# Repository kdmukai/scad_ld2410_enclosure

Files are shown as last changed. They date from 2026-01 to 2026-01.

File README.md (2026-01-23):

# ld2410 Human Presence Sensor Enclosure

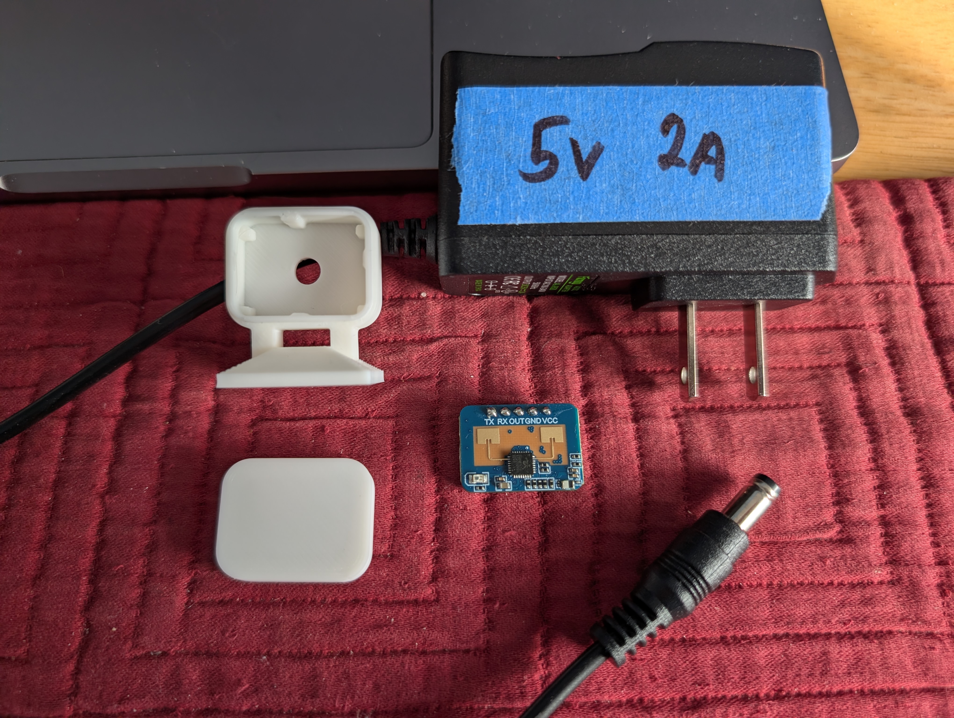
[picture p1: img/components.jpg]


The ld2410 sensor detects human presence even without movement. It broadcasts its data over bluetooth so it can be put to use as a standalone device with just a 5V power supply.

You can then read in the sensor data over bluetooth into Home Assistant to use in automations.

You can also directly connect an ld2410 to an esp32 via ESPHome and receive the data over UART rx/tx, but I find the simplicity of bluetooth to be preferrable (and it's only 2 wires -- VCC and GND -- vs 4 for UART). 

The placement of these sensors around the house is also much more flexible if they are just self-powered and self-broadcasting.

The 3d printed lid does not interfere with its detection abilities.

---

### Design variations
3d printable files include three variants:
* Freestanding pedestal
* Corner wall mount
* Flush wall mount

I used double-sided tape for the wall mounts and under the pedestal to keep it in place.

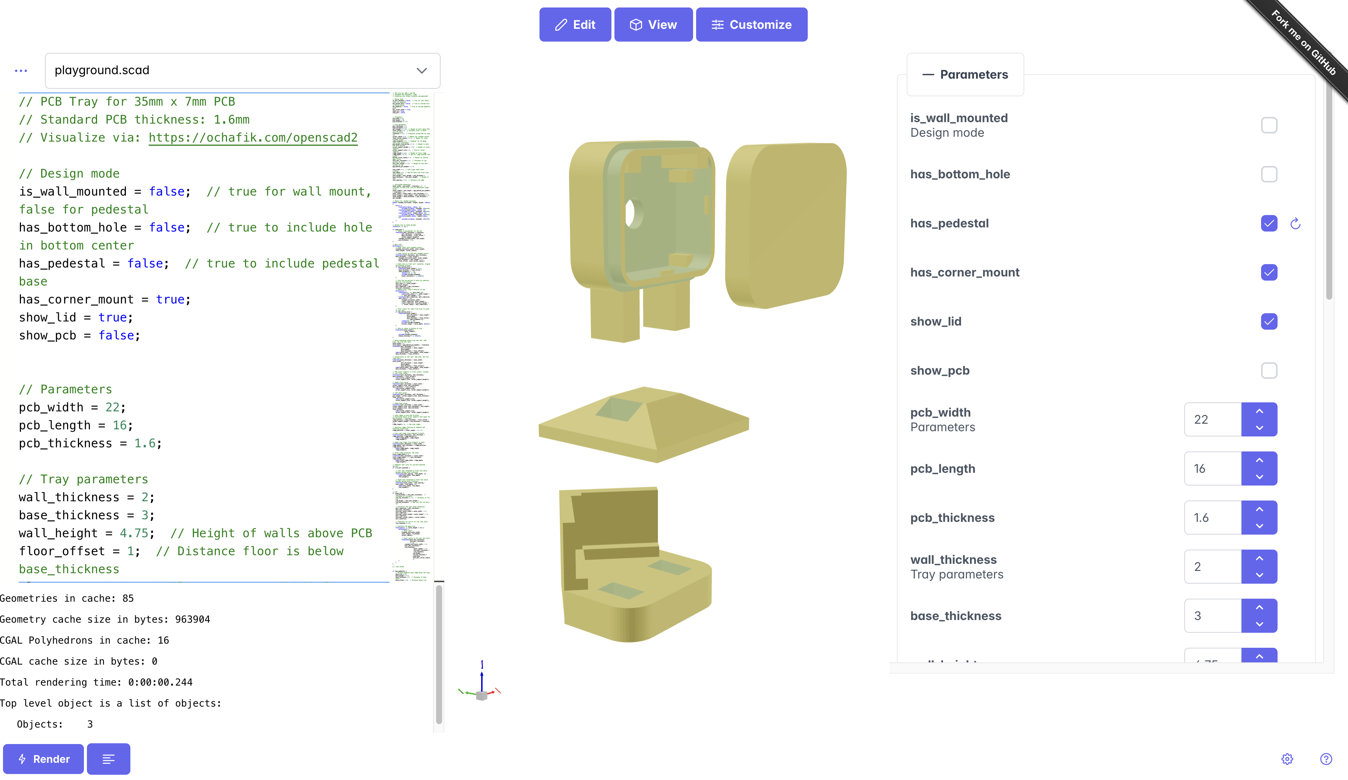
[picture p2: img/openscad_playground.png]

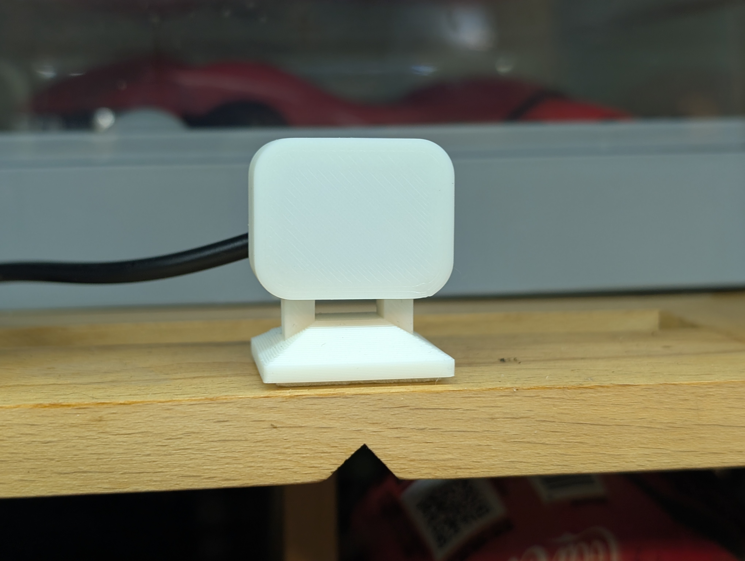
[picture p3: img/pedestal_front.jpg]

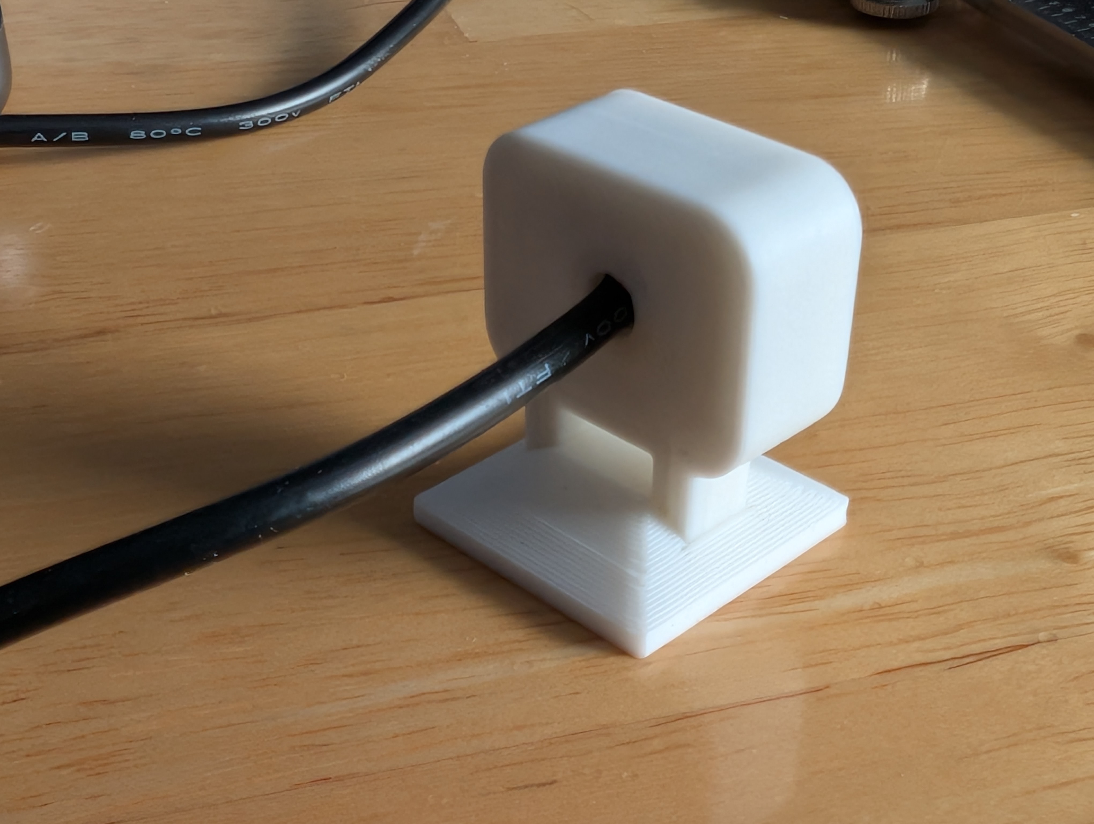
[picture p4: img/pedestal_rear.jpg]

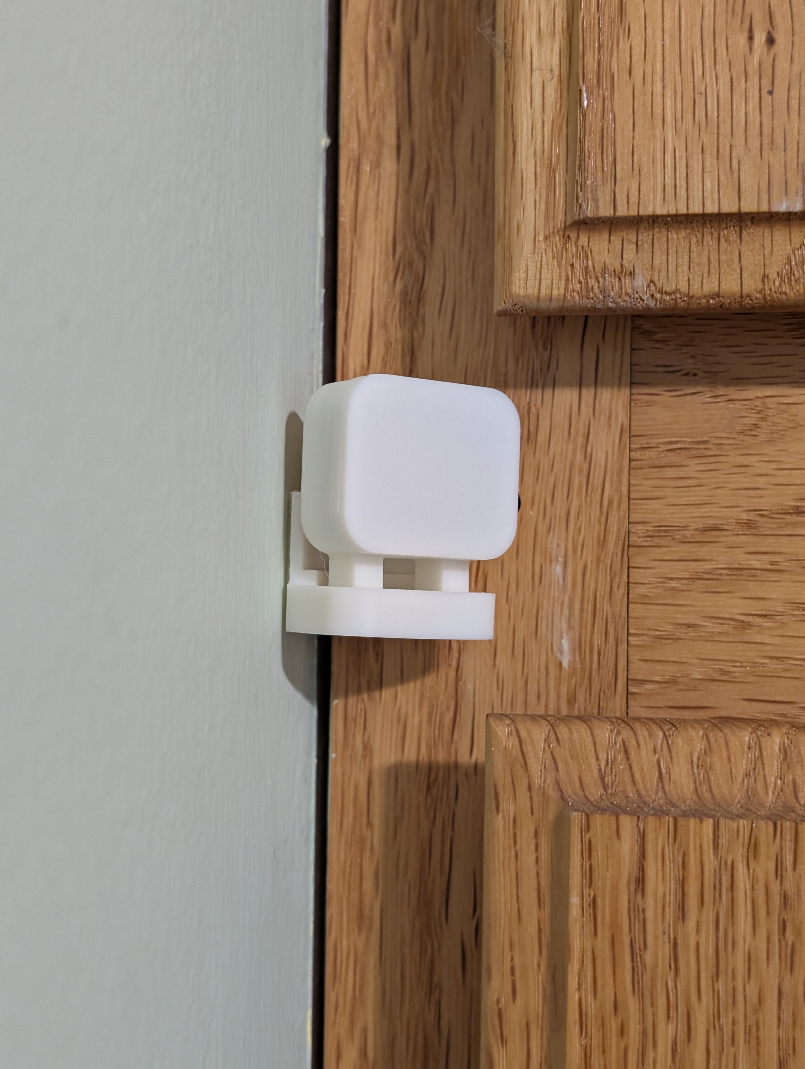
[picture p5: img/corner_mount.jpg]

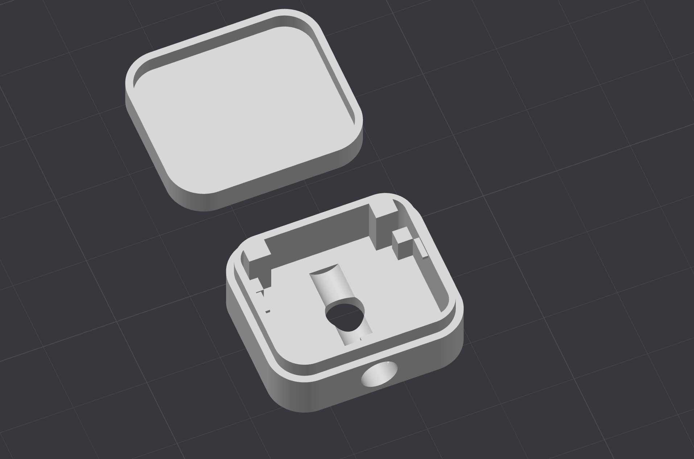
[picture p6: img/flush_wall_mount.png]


---

### Files
* [Customizable SCAD](files/ld2410_enclosure.scad)
* [All variants 3MF](files/ld2410_enclosure.3mf)
* STLs:
  * [Enclosure with feet](files/enclosure_with_feet.stl)
  * [Pedestal](files/pedestal.stl)
  * [Corner mount](files/corner_mount.stl)
  * [Flush wall mount enclosure](files/flush_wall_enclosure.stl)

---

### Components
* ld2410 human presence sensor
* 5V power supply
* solid core 20-22ga patching wire
* soldering iron, solder sucker, solder, flux
* pliers, wire stripper, wire/pin cutter

___

### Assembly
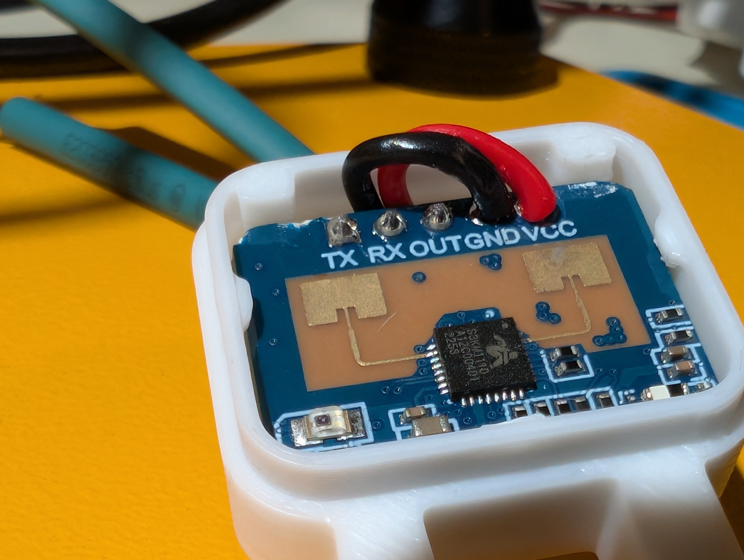
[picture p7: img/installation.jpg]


Remove the black plastic around the headers using a pair of pliers.

Desolder the GND and VCC pins (see [this tutorial](https://www.youtube.com/watch?v=ATeRNgOUX3o&t=114s) for help).

Cut off the remaining pins.

Feed solid core wire through the pin holes and solder in place. I found it easier to apply flux to the back side of the pcb and solder the wires there; soldering them at the front side of the board did not take the flux as easily due to existing solder residue.

Snap the ld2410 into place. There is clearance at the top edge of the board to pass the wires through.

Feed the wires through the enclosure's exit hole.

I then cut off the barrel connector from the power supply and then soldered the leads to the solid core wires and sealed them with heat shrink tubing.

---

### Configuration and Communication
Position the sensor and then adjust its range and sensitivity using the HLKRadarTool app ([Android](https://play.google.com/store/apps/details?id=com.hlk.hlkradartool&hl=en_US), [iOS](https://apps.apple.com/us/app/hlkradartool/id1638651152)).

I set up a `bluetooth_proxy` in ESPHome so that a wifi-connected esp32-s3 uses its antenna to both communicate with Home Assistant and relay data from bluetooth devices.

Home Assistant has a HACS integration to read this bluetooth sensor data: `ha-ld2410`. See: https://www.youtube.com/watch?v=7-VV-X5BpNo

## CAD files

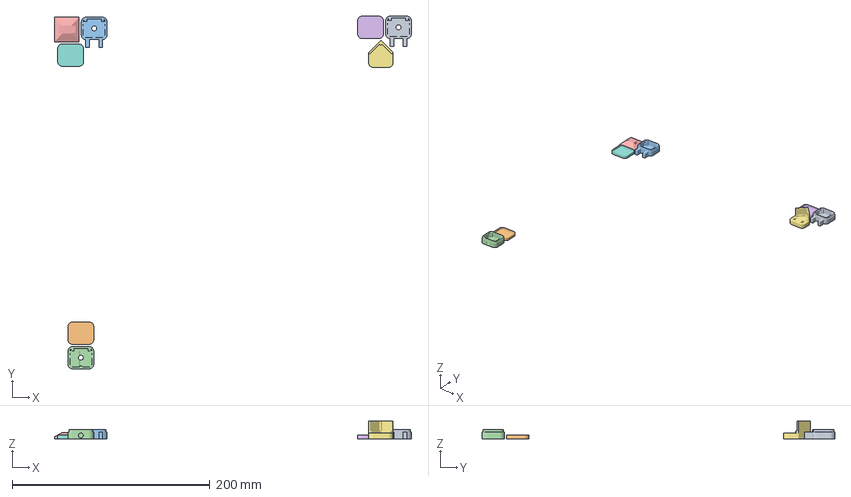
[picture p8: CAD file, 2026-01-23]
files/ld2410_enclosure.3mf
361.1 x 357.0 x 18.1 mm
export (29).stl x 7
export (30).stl

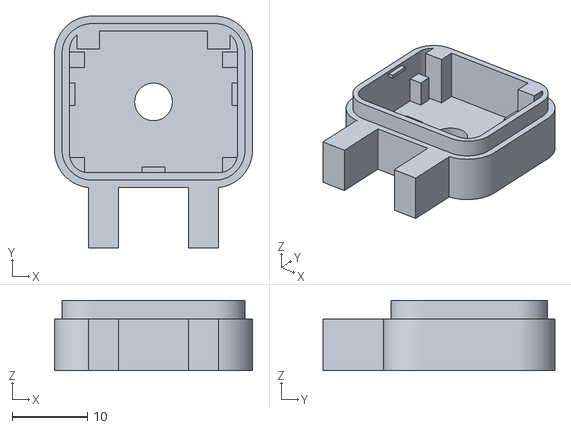
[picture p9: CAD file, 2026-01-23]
files/enclosure_with_feet.stl
26.3 x 30.8 x 9.35

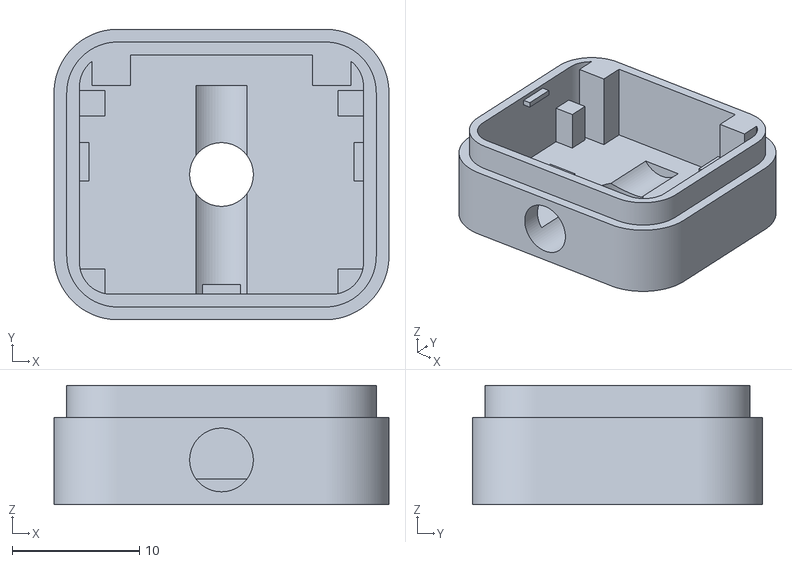
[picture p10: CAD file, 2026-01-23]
files/flush_wall_enclosure.stl
26.3 x 22.8 x 9.35

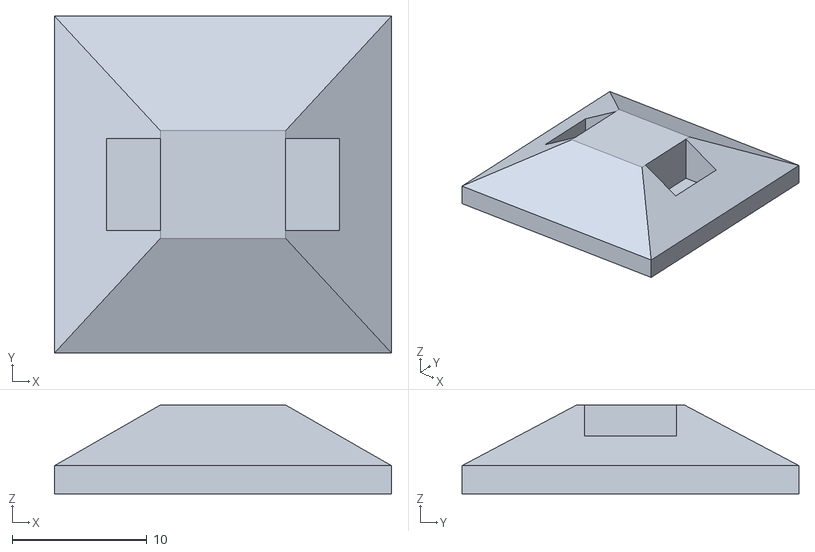
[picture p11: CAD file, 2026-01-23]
files/pedestal.stl
25.0 x 25.0 x 6.60

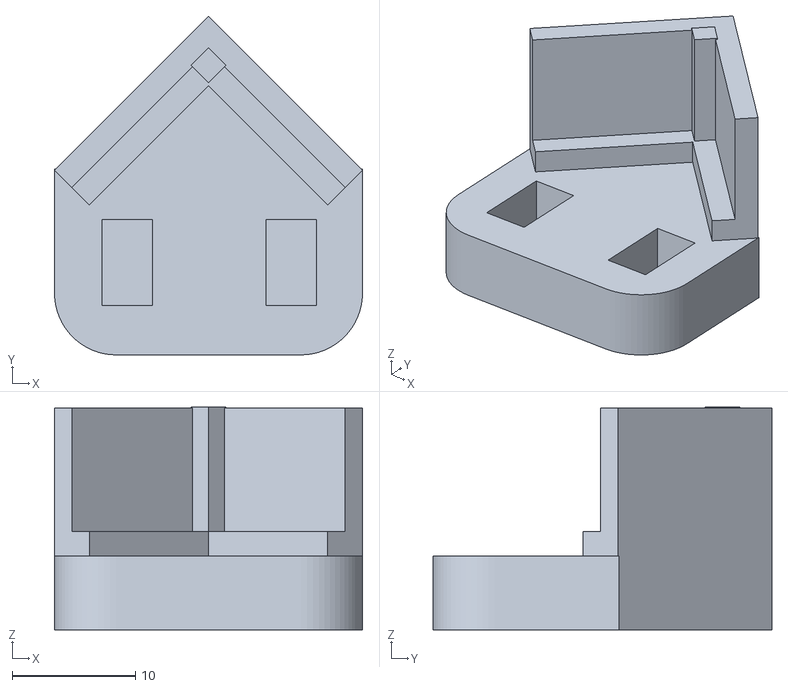
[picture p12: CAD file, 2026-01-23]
files/corner_mount.stl
25.0 x 27.5 x 18.1

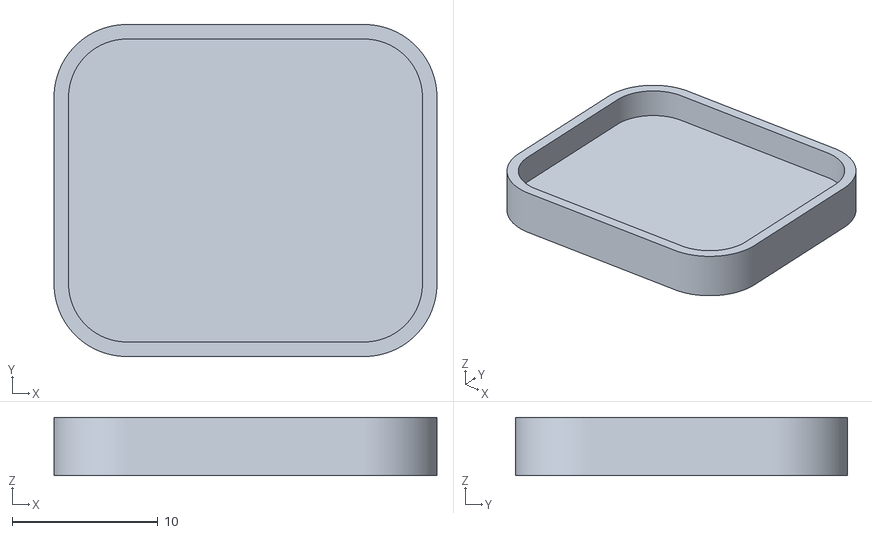
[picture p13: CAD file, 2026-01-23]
files/lid.stl
26.3 x 22.8 x 4.00

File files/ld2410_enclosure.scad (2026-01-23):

// PCB Tray for 35mm x 7mm PCB
// Standard PCB thickness: 1.6mm
// Visualize via: https://ochafik.com/openscad2

// Design mode
is_wall_mounted = false;  // true for wall mount, false for pedestal
has_bottom_hole = false;  // true to include hole in bottom center
has_pedestal = false;  // true to include pedestal base
has_corner_mount = true;
show_lid = true;
show_pcb = false;


// Parameters
pcb_width = 22;
pcb_length = 16;
pcb_thickness = 1.6;

// Tray parameters
wall_thickness = 2;
base_thickness = 3;
wall_height = 4.75;  // Height of walls above PCB
floor_offset = 1;  // Distance floor is below base_thickness
clearance = 0.1;  // Clearance around PCB for easy fit
corner_radius = 5;  // Radius for rounded corners
inner_corner_radius = 2.5;  // Radius for inner rounded corners
cable_diameter = 5;  // Diameter for 20 gauge cable with insulation
pcb_height_from_bottom = 2.5;  // Height to hold PCB above bottom
corner_support_height = 3.75;  // Height of corner supports
corner_support_size = 2;  // Size of corner supports
ridge_height = 0.5;  // Height of front ridge
ridge_depth = 0.75;  // How far ridge extends into cavity
bottom_fillet_radius = 1;  // Radius for bottom edge fillet
thin_wall_thickness = 1;  // Thickness of top portion of walls
thin_wall_height = 2.5;  // Height of thin wall section at top
gap_behind_pin_headers = 2.5;

foot_width = 4;  // Left-right width after rotation
foot_depth = 8;  // How far back from front face after rotation
foot_height = wall_height + pcb_thickness + base_thickness - thin_wall_height;  // Height of feet
foot_spacing = 4.5;  // Distance from edge


// Calculated dimensions
inner_width = pcb_width + clearance * 3;  // clearance on each side, plus an additional fudge factor
inner_length = pcb_length + gap_behind_pin_headers + clearance * 3;
outer_width = inner_width + wall_thickness * 2;
outer_length = inner_length + wall_thickness * 2;
total_height = base_thickness + pcb_thickness + wall_height;

// Module for rounded rectangle
module rounded_rect(width, length, height, radius) {
    hull() {
        translate([radius, radius, 0])
            cylinder(r=radius, h=height, $fn=150);
        translate([width-radius, radius, 0])
            cylinder(r=radius, h=height, $fn=150);
        translate([radius, length-radius, 0])
            cylinder(r=radius, h=height, $fn=150);
        translate([width-radius, length-radius, 0])
            cylinder(r=radius, h=height, $fn=150);
    }
}

// Rotate tray to stand upright
rotate([90, 0, 0]) {

if (show_pcb) {
    // Render a placeholder for the pcb
    translate([wall_thickness + clearance, 
            wall_thickness + clearance, 
            base_thickness - floor_offset + corner_support_height])
        rounded_rect(pcb_width, pcb_length, pcb_thickness, 2.5);
}

// Main tray
difference() {
    // Outer shell with rounded corners
    rounded_rect(outer_width, outer_length, total_height, corner_radius);
    
    // Inner cavity for PCB with rounded corners
    translate([wall_thickness, wall_thickness, base_thickness - floor_offset])
        rounded_rect(inner_width, inner_length, pcb_thickness + wall_height + 1 + floor_offset, inner_corner_radius);
    
    // Cable hole in front wall (centered, aligned with bottom surface)
    if (has_bottom_hole) {
        translate([outer_width/2, -0.5, base_thickness - floor_offset + cable_diameter/2 - 1])
            rotate([-90, 0, 0])
            cylinder(d=cable_diameter, h=wall_thickness + 1, $fn=64);
    }
    
    // Thin the top portion of walls by removing material from outside
    thin_start_z = total_height - thin_wall_height;
    wall_reduction = wall_thickness - thin_wall_thickness;
    // Remove outer ring of material at top
    difference() {
        translate([-1, -1, thin_start_z])
            cube([outer_width + 2, outer_length + 2, thin_wall_height + 1]);
        translate([wall_reduction, wall_reduction, thin_start_z - 1])
            rounded_rect(outer_width - 2*wall_reduction, outer_length - 2*wall_reduction, thin_wall_height + 2, corner_radius - wall_reduction);
    }
    
    // Floor cutout for cable from front to notch in rear wall
    if (has_bottom_hole) {
        translate([outer_width/2,
                   wall_thickness + inner_length - notch_depth,
                   base_thickness - floor_offset - 1 + cable_diameter/2])
            rotate([90, 0, 0])
            cylinder(d=cable_diameter, h=inner_length - notch_depth, $fn=64);
    }
    
    // Hole in center of bottom of tray
    translate([outer_width/2,
                outer_length/2,
                -0.5])
        cylinder(d=cable_diameter, h=base_thickness + 1, $fn=64);
}

// Notch extending inward from rear wall (3mm wide, 1mm from left wall)
notch_width = 3;
notch_depth = gap_behind_pin_headers - clearance;
translate([wall_thickness + 1,
           wall_thickness + inner_length - notch_depth,
           base_thickness - floor_offset])
    cube([notch_width, notch_depth, total_height - base_thickness + floor_offset]);

// Second notch on rear wall (3mm wide, 1mm from right wall)
translate([wall_thickness + inner_width - notch_width - 1,
           wall_thickness + inner_length - notch_depth,
           base_thickness - floor_offset])
    cube([notch_width, notch_depth, total_height - base_thickness + floor_offset]);

// PCB corner supports in front corners (inside)
// Left front corner
translate([wall_thickness, wall_thickness, base_thickness - floor_offset])
    cube([corner_support_size, corner_support_size, corner_support_height]);

// Right front corner
translate([wall_thickness + inner_width - corner_support_size, wall_thickness, base_thickness - floor_offset])
    cube([corner_support_size, corner_support_size, corner_support_height]);

// Left back corner
translate([wall_thickness, wall_thickness + pcb_length - corner_support_size, base_thickness - floor_offset])
    cube([corner_support_size, corner_support_size, corner_support_height]);

// Right back corner
translate([wall_thickness + inner_width - corner_support_size, wall_thickness + pcb_length - corner_support_size, base_thickness - floor_offset])
    cube([corner_support_size, corner_support_size, corner_support_height]);

// Side ridges to hold PCB in place
// Positioned above corner supports with space for PCB thickness + clearance
ridge_bottom_z = base_thickness - floor_offset + corner_support_height + pcb_thickness + clearance + 1;
ridge_length = 3;  // 3mm long ridges

// Position ridges starting at midpoint and extending toward back
ridge_position = (inner_length - 1) / 2;

// Left side ridge (from midpoint to back)
translate([wall_thickness, wall_thickness + ridge_position, ridge_bottom_z])
    cube([ridge_depth, ridge_length, ridge_height]);

// Right side ridge (from midpoint to back)
translate([wall_thickness + inner_width - ridge_depth, wall_thickness + ridge_position, ridge_bottom_z])
    cube([ridge_depth, ridge_length, ridge_height]);

// Front ridge (centered, 3mm wide)
front_ridge_width = 3;
translate([wall_thickness + (inner_width - front_ridge_width) / 2, wall_thickness, ridge_bottom_z])
    cube([front_ridge_width, ridge_depth, ridge_height]);

// Pedestal feet (only for non-wall-mounted version)
if (!is_wall_mounted) {
    
    // Left foot (attached to front face which becomes bottom after rotation)
    translate([foot_spacing, -foot_depth, 0])
        cube([foot_width, foot_depth, foot_height]);
    
    // Right foot (attached to front face which becomes bottom after rotation)
    translate([outer_width - foot_spacing - foot_width, -foot_depth, 0])
        cube([foot_width, foot_depth, foot_height]);
}

// Lid
if (show_lid) {
    lid_thickness = thin_wall_thickness;  // Thickness of lid walls
    lid_top_thickness = 1.5;  // Thickness of lid top
    lid_height = thin_wall_height + lid_top_thickness;  // How tall the lid walls are
    
    // Calculate thin wall outer dimensions
    wall_reduction = wall_thickness - thin_wall_thickness;
    thin_wall_outer_width = outer_width - 2 * wall_reduction;
    thin_wall_outer_length = outer_length - 2 * wall_reduction;
    thin_wall_corner_radius = corner_radius - wall_reduction;
    
    // Clearance for lid to fit over thin walls
    lid_clearance = 0.0;
    
    // Position lid above tray
    translate([0, 0, total_height + 20]) {
        difference() {
            // Outer shell
            rounded_rect(outer_width, outer_length, lid_height, corner_radius);
            
            // Inner cavity to fit over thin walls
            translate([thin_wall_thickness, 
                       thin_wall_thickness, 
                       -0.1])
                rounded_rect(outer_width - 2 * thin_wall_thickness + lid_clearance, 
                            outer_length - 2 * thin_wall_thickness + lid_clearance, 
                           lid_height - lid_top_thickness + clearance, 
                           thin_wall_corner_radius);
        }
    }
}

} // End rotate
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

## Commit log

2026-01-23 tweaks after installation tests
    [ld2410_enclosure.scad]
2026-01-23 STLs added
    [corner_mount.stl, enclosure_with_feet.stl, flush_wall_enclosure.stl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]
